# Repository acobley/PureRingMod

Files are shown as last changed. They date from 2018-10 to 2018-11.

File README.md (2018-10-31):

View this project on [CADLAB.io](https://cadlab.io/project/1337). 

# PureRingMod
A Eurorack ring modulator.

1:  Balanced input suitable for a SM58 
2: Carrier and Mod levels should accept 10Vpp.   Level controls on each.
3: Mixer on Mic in and Carrier
4: Mixer on the output of the ring mod chip and Carrier in.  This allows the uint to act as a mic input to eurorack
5: Gain control on the output stage, I found this useful to avoid clipping on the output
6: Dual output sockets.  It's a bugbear of mine that more modules don't have dual output to avoid having to use a splitter module to send the signal to more than one output.

Design Andy C
From a design by Roman Sowa
CC BY 3.0

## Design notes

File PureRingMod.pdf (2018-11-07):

Qty Parts | Description | Value | Package | RS-PART
2 C1, C4 | 10.0¬µF polarized capacitors | 10uF | CPOL-RADIAL-2.5MM-5MM
3 CARRIER, MODULATOR, OUTPUT | | PJ301M-12 | S_JACK
2 D1, D2 | Diode | 1N4148 | DO-1N4148 | 671-5477
5 GAIN, MICMIX, MIX, VOLCARIER, VOLMOD | 100K | Alpha Vertical Potentiometer
1 IC1 | OP AMP | TL074P | DIL14
1 IC2 | OP AMP | TL072P | DIL08
1 MP1 | | AD633AN | DIL08
1 OUTPUT2 | | Output2 | S_JACK
1 POWER | Header 5x2 | M05X2SHD | 2X5-SHROUDED
1 R1 | Resistor | 100K | AXIAL-0.3
1 R10 | Resistor | 27K | AXIAL-0.3
2 R11, R12 | Resistor | 1M | AXIAL-0.3
1 R15 | Resistor | 20K | AXIAL-0.3
3 R2, R13, R16 | Resistor | 10K | AXIAL-0.3
2 R3, R4 | Resistor | 4k7 | AXIAL-0.3
2 R5, R6 | Resistor | 1K | AXIAL-0.3
2 R8, R9 | Resistor | 330 | AXIAL-0.3
1 X1 | Neutrik Audio Connector XLR SERIES NC3FD-V | NC3FD-V | 448-244

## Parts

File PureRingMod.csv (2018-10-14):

Library | Qty | Parts | Description | Value | Package | MF | MPN | OC_FARNELL | OC_NEWARK | PROD_ID | RS-PART | VALUE
INSTRUO | 3 | CARRIER, MODULATOR, OUTPUT |  |  | S_JACK
INSTRUO | 2 | CARRIERAC, MODAC |  |  | TOGGLE_ON_OFF_ON
GMSN | 4 | MICMIX, MIX, VOLCARIER, VOLMOD |  | 9MMPOT | POT
ad633-2 | 1 | MP1 |  | AD633AN | DIL08
SparkFun-Capacitors | 2 | C2, C3 | 0.1µF ceramic capacitors | 1uF | CAP-PTH-SMALL-KIT |  |  |  |  | CAP-08370 |  | 0.1uF
SparkFun-Capacitors | 1 | C5 | 0.1µF ceramic capacitors | 4u7f | CAP-PTH-SMALL-KIT |  |  |  |  | CAP-08370 |  | 0.1uF
SparkFun-Capacitors | 2 | C1, C4 | 10.0µF polarized capacitors | 10uF | CPOL-RADIAL-2.5MM-5MM |  |  |  |  | CAP-08440 |  | 10uF
SparkFun-Resistors | 1 | R14 | 330Ω resistor | 100 | AXIAL-0.3 |  |  |  |  | RES-8371 |  | 330
SparkFun-Resistors | 2 | R1, R16 | 330Ω resistor | 100K | AXIAL-0.3 |  |  |  |  | RES-8371 |  | 330
SparkFun-Resistors | 1 | R13 | 330Ω resistor | 10K | AXIAL-0.3 |  |  |  |  | RES-8371 |  | 330
SparkFun-Resistors | 1 | R5 | 330Ω resistor | 1K | AXIAL-0.3 |  |  |  |  | RES-8371 |  | 330
SparkFun-Resistors | 4 | R6, R7, R11, R12 | 330Ω resistor | 1M | AXIAL-0.3 |  |  |  |  | RES-8371 |  | 330
SparkFun-Resistors | 2 | R2, R15 | 330Ω resistor | 20K | AXIAL-0.3 |  |  |  |  | RES-8371 |  | 330
SparkFun-Resistors | 1 | R10 | 330Ω resistor | 27K | AXIAL-0.3 |  |  |  |  | RES-8371 |  | 330
SparkFun-Resistors | 2 | R8, R9 | 330Ω resistor | 330 | AXIAL-0.3 |  |  |  |  | RES-8371 |  | 330
SparkFun-Resistors | 2 | R3, R4 | 330Ω resistor | 4k7 | AXIAL-0.3 |  |  |  |  | RES-8371 |  | 330
adafruit | 2 | D1, D2 | Diode |  | DO-1N4148
SparkFun-Connectors | 1 | POWER | Header 5x2 | M05X2SHD | 2X5-SHROUDED
con-neutrik_ag | 1 | X1 | Neutrik Audio Connector XLR SERIES | NC3FD-V | NC3FD-V | FARNELL | NC3FDV | 308869 | 07WX7308 |  | 448-244
GMSN-R2Project | 1 | IC2 | OP AMP | TL072P | DIL08
GMSN | 1 | IC1 | OP AMP | TL074P | DIL14

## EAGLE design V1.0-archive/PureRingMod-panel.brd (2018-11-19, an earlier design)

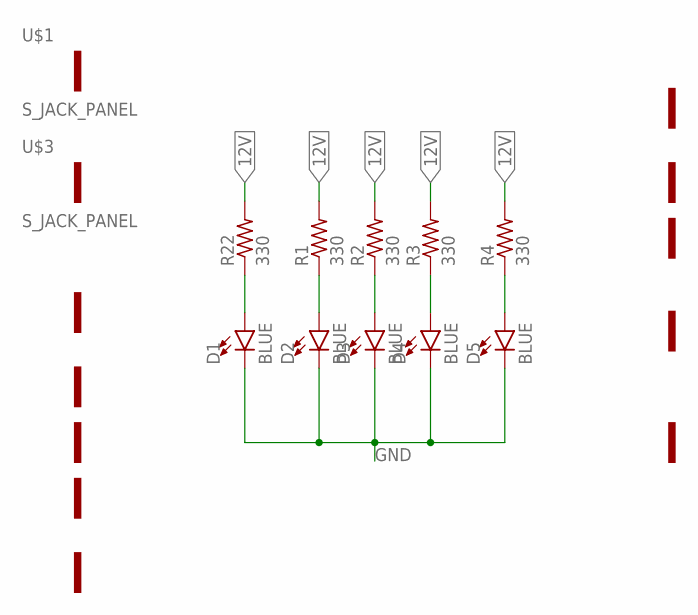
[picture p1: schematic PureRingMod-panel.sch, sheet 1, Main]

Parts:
D1, D2, D3, D4, D5: BLUE; LED-1206
R1, R2, R3, R4, R22: 330; R0805
U$1, U$3: S_JACK_PANEL
U$6, U$7, U$8, U$9, U$10: POT_PANEL
U$11: XLR_PANEL
U$12, U$13, U$14, U$15: MOUNTING_HOLE

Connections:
12V: R1.2, R2.2, R3.2, R4.2, R22.2; also elsewhere on the board
GND: D1.C, D2.C, D3.C, D4.C, D5.C; also elsewhere on the board
unnamed: D1.A, R22.1
unnamed: D2.A, R1.1
unnamed: D3.A, R2.1
unnamed: D4.A, R3.1
unnamed: D5.A, R4.1

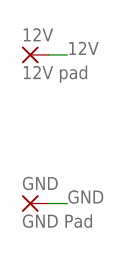
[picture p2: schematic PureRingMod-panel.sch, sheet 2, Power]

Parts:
12V: 12V pad; 1,6/0,8
GND: GND Pad; 1,6/0,8

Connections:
12V: 12V.1; also elsewhere on the board
GND: GND.1; also elsewhere on the board

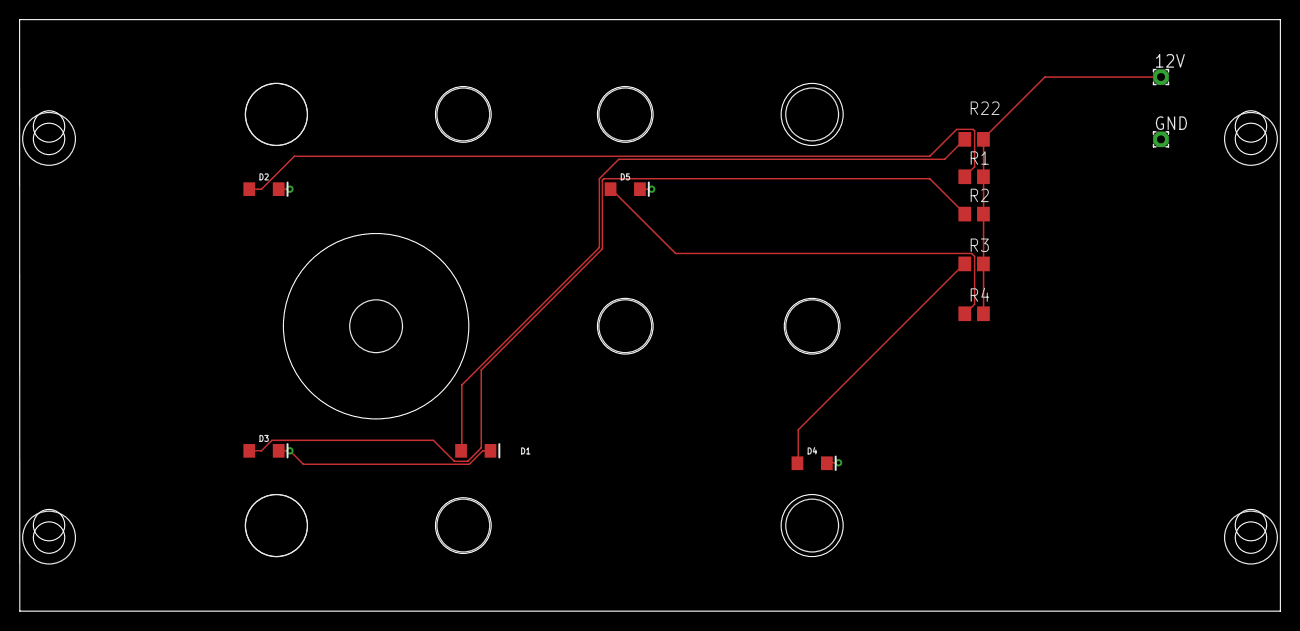
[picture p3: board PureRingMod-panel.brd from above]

Board: 2 copper layers, 128.5 x 60.3 mm, 27 parts (1 on the bottom side), 7 nets.

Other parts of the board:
U$2: GMSN!_LOGO
U$4, U$5: S_JACK_PANEL; S_JACK_PANEL@1

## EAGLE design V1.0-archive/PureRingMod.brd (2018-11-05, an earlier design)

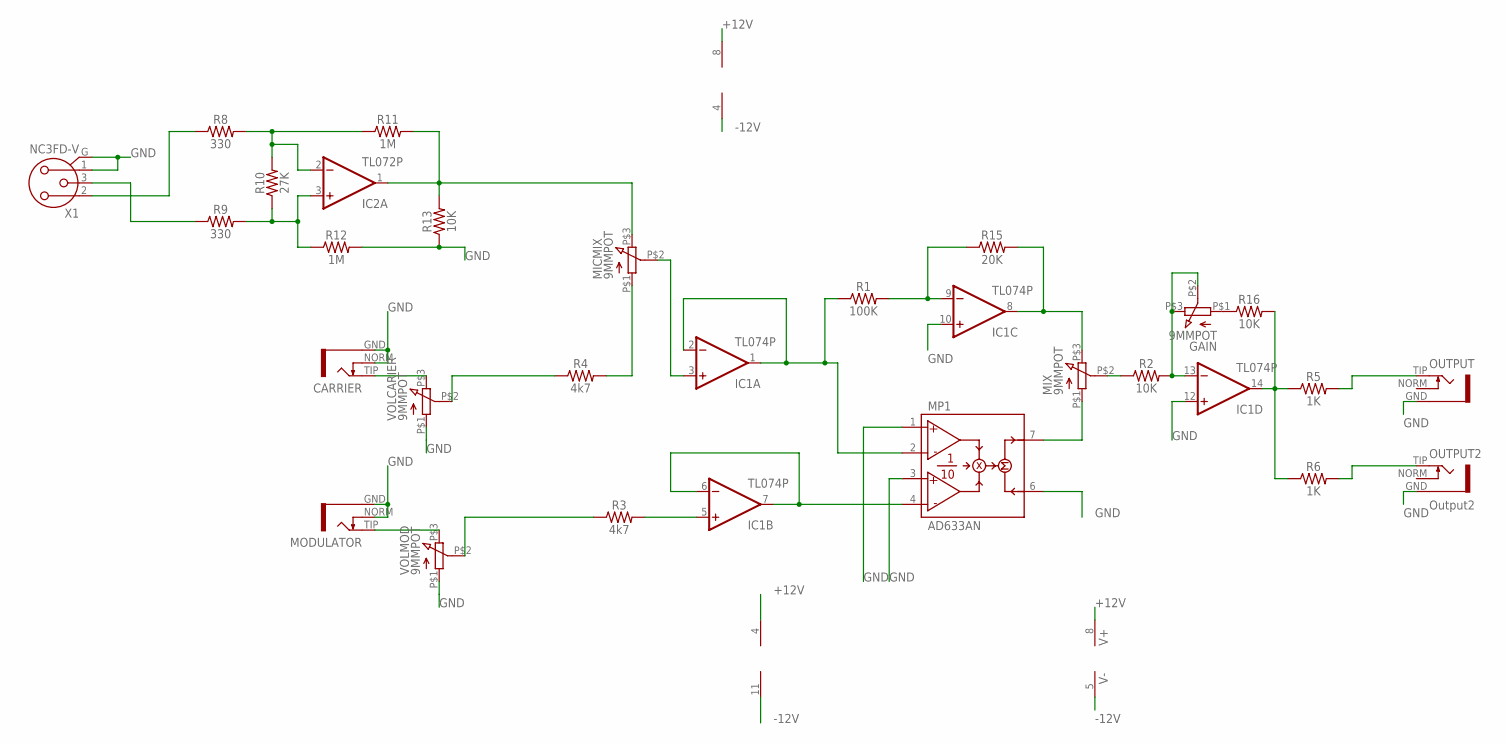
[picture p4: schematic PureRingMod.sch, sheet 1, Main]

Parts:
CARRIER: S_JACK
GAIN: 9MMPOT; POT
IC1: TL074P; DIL14
IC2: TL072P; DIL08
MICMIX: 9MMPOT; POT
MIX: 9MMPOT; POT
MODULATOR: S_JACK
MP1: AD633AN; DIL08
OUTPUT: S_JACK
OUTPUT2: Output2; S_JACK
R1: 100K; AXIAL-0.3
R2, R13, R16: 10K; AXIAL-0.3
R3, R4: 4k7; AXIAL-0.3
R5, R6: 1K; AXIAL-0.3
R8, R9: 330; AXIAL-0.3
R10: 27K; AXIAL-0.3
R11, R12: 1M; AXIAL-0.3
R15: 20K; AXIAL-0.3
VOLCARIER: 9MMPOT; POT
VOLMOD: 9MMPOT; POT
X1: NC3FD-V

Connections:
+12V: IC1.4 (V+), IC2.8 (V+), MP1.8 (V+); also elsewhere on the board
-12V: IC1.11 (V-), IC2.4 (V-), MP1.5 (V-); also elsewhere on the board
GND: CARRIER.GND, CARRIER.NORM, IC1.10 (+IN), IC1.12 (+IN), MODULATOR.GND, MODULATOR.NORM, MP1.1 (X1), MP1.3 (Y1), MP1.6 (Z), OUTPUT.GND, OUTPUT2.GND, R12.P$2 (2), R13.P$1 (1), VOLCARIER.P$1 (1), VOLMOD.P$1 (1), X1.1 (2), X1.G; also elsewhere on the board
unnamed: IC1.1 (OUT), IC1.2 (-IN), MP1.2 (X2), R1.P$1 (1)
unnamed: IC1.6 (-IN), IC1.7 (OUT), MP1.4 (Y2)
unnamed: MIX.P$1 (1), MP1.7 (W)
unnamed: IC1.8 (OUT), MIX.P$3 (3), R15.P$2 (2)
unnamed: GAIN.P$1 (1), R16.P$1 (1)
unnamed: MIX.P$2 (2), R2.P$1 (1)
unnamed: GAIN.P$2 (2), GAIN.P$3 (3), IC1.13 (-IN), R2.P$2 (2)
unnamed: MICMIX.P$1 (1), R4.P$2 (2)
unnamed: IC1.5 (+IN), R3.P$2 (2)
unnamed: IC1.14 (OUT), R5.P$1 (1), R6.P$1 (1), R16.P$2 (2)
unnamed: IC1.9 (-IN), R1.P$2 (2), R15.P$1 (1)
unnamed: OUTPUT.TIP, R5.P$2 (2)
unnamed: CARRIER.TIP, VOLCARIER.P$3 (3)
unnamed: MODULATOR.TIP, VOLMOD.P$3 (3)
unnamed: R4.P$1 (1), VOLCARIER.P$2 (2)
unnamed: R3.P$1 (1), VOLMOD.P$2 (2)
unnamed: OUTPUT2.TIP, R6.P$2 (2)
unnamed: R8.P$1 (1), X1.2 (1)
unnamed: R9.P$1 (1), X1.3
unnamed: IC2.2 (-IN), R8.P$2 (2), R10.P$2 (2), R11.P$1 (1)
unnamed: IC2.3 (+IN), R9.P$2 (2), R10.P$1 (1), R12.P$1 (1)
unnamed: IC2.1 (OUT), MICMIX.P$3 (3), R11.P$2 (2), R13.P$2 (2)
unnamed: IC1.3 (+IN), MICMIX.P$2 (2)

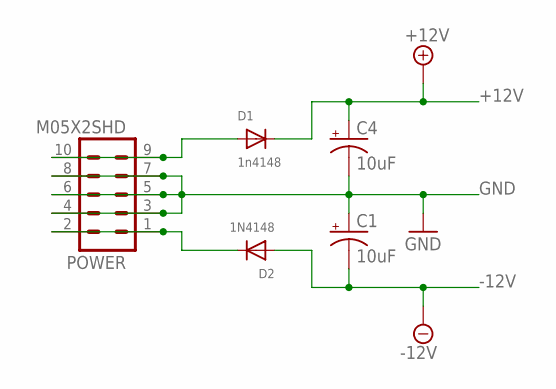
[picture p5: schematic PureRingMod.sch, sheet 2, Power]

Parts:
C1, C4: 10uF; CPOL-RADIAL-2.5MM-5MM
D1: 1n4148; DO-1N4148
D2: 1N4148; DO-1N4148
POWER: M05X2SHD; 2X5-SHROUDED

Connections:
+12V: C4.1 (+), D1.C; also elsewhere on the board
-12V: C1.2 (-), D2.A; also elsewhere on the board
GND: C1.1 (+), C4.2 (-), POWER.3, POWER.4, POWER.5, POWER.6, POWER.7, POWER.8; also elsewhere on the board
unnamed: D1.A, POWER.9, POWER.10
unnamed: D2.C, POWER.1, POWER.2

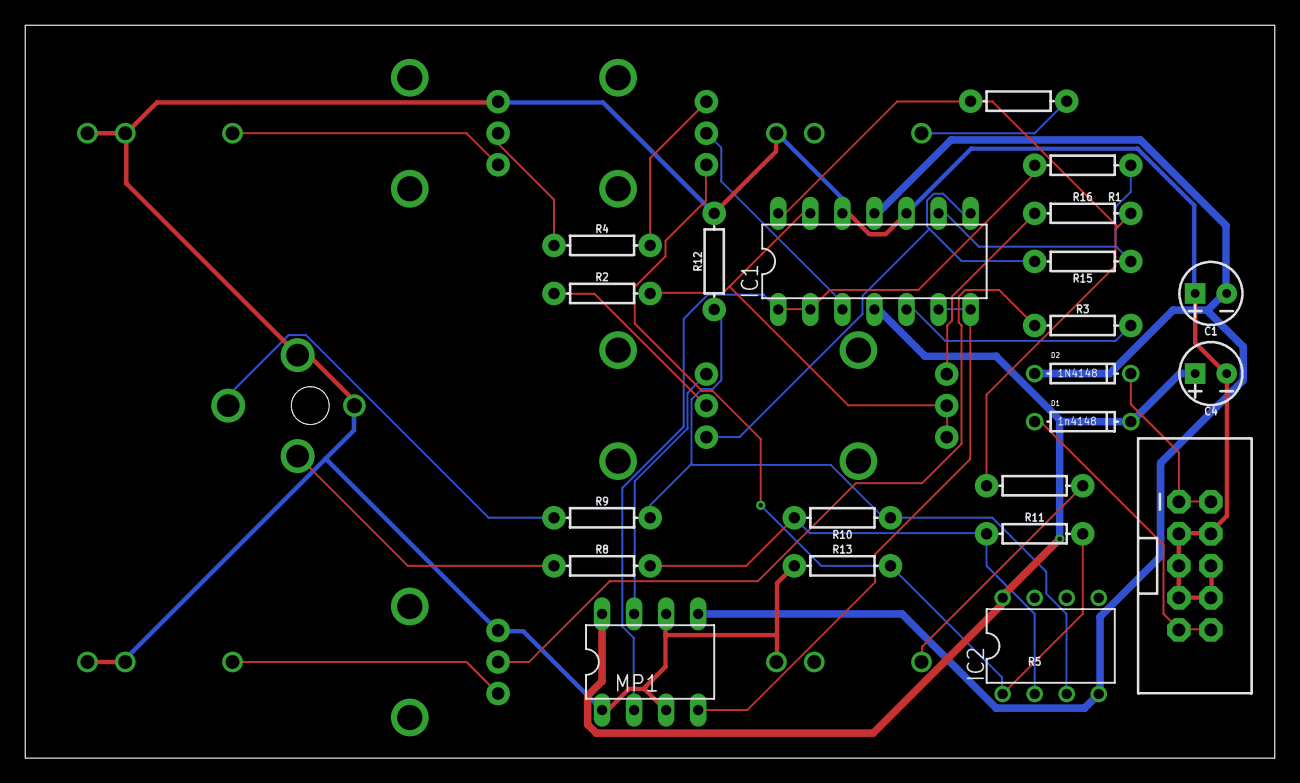
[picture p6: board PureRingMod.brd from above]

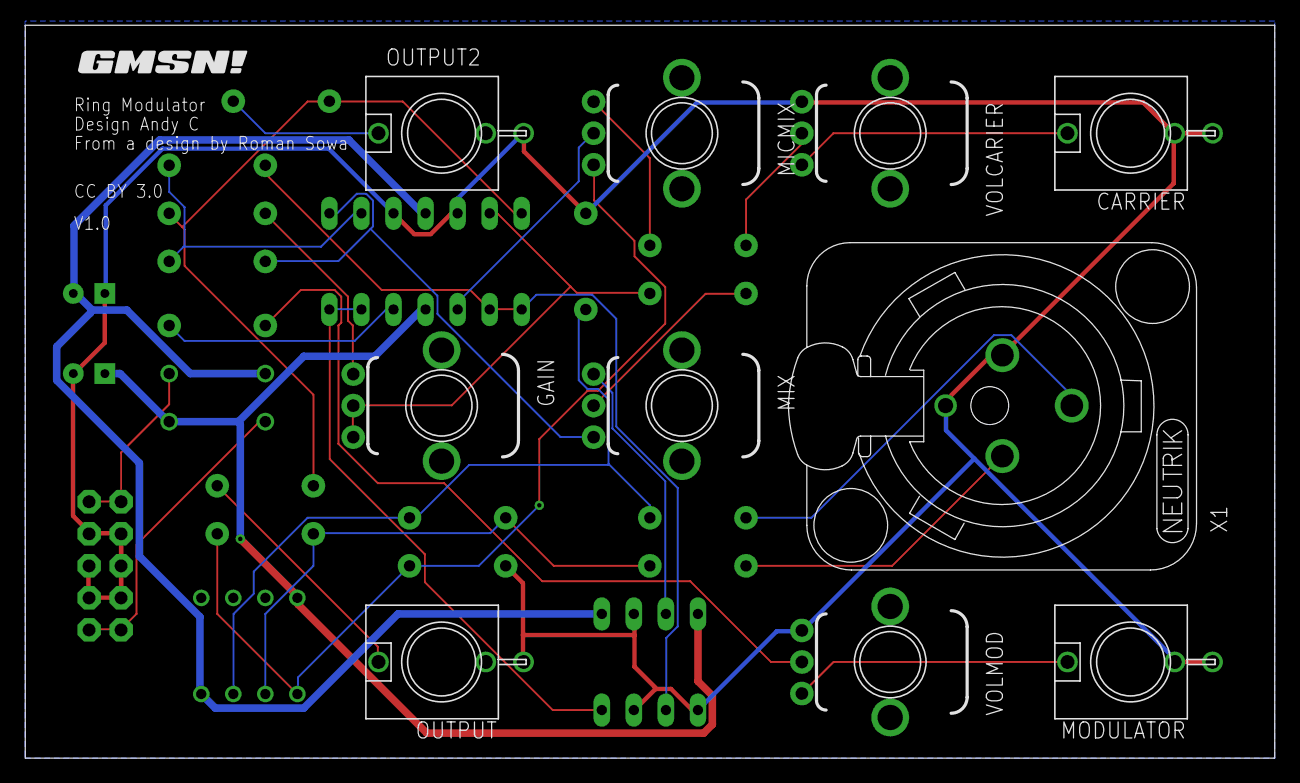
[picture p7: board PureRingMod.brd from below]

Board: 2 copper layers, 99.0 x 58.1 mm, 33 parts (11 on the bottom side), 28 nets.

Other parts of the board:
U$2: GMSN!_LOGO

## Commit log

2018-10-03 Init design
    [PureRingMod.brd, PureRingMod.sch]
2018-10-03 Power to TL072
2018-10-13 added mix control
    [PureRingMod.brd, PureRingMod.sch]
2018-10-13 Added input circuit emualtion for use in https://www.falstad.com/circuit/
2018-10-13 updated components in feedback circuit of preamp
    [PureRingMod.brd, PureRingMod.sch]
2018-10-13 Corrected values on input circuit
    [PureRingMod.brd, PureRingMod.sch]
2018-10-13 corrected input components
    [PureRingMod.brd, PureRingMod.sch]
2018-10-14 added missing parts
    [PureRingMod.brd, PureRingMod.csv, PureRingMod.sch]
2018-10-14 Changed output circuit values
    [PureRingMod.brd, PureRingMod.csv, PureRingMod.sch]
2018-10-14 modified input mic circuit
    [PureRingMod.brd, PureRingMod.csv, PureRingMod.sch]
2018-10-14 Fixed input
    [PureRingMod.brd, PureRingMod.sch]
2018-10-14 Fixed output socket
    [PureRingMod.brd, PureRingMod.sch]
2018-10-19 fixed -12V to Tl074
    [PureRingMod.brd, PureRingMod.sch]
2018-10-19 removed ac/Dc switched input
    [PureRingMod.brd, PureRingMod.sch]
2018-10-19 ripped up board
    [PureRingMod.brd]
2018-10-21 Fixed wiring errors
    [PureRingMod.brd, PureRingMod.sch]
2018-10-27 updated board
    [PureRingMod.brd]
2018-10-31 V1.0 board
    [PureRingMod.brd, PureRingMod.sch]
2018-11-01 added panel design (PCB)
    [PureRingMod-panel.brd, PureRingMod-panel.sch]
2018-11-01 Panel Design
    [PureRingMod-panel.brd]
2018-11-03 design of panel
    [PureRingMod-panel.brd, PureRingMod.brd]
2018-11-05 added BOM
    [PureRingMod.xlsx]
2018-11-05 updated BOM
    [PureRingMod.brd, PureRingMod.sch, PureRingMod.xlsx]
2018-11-07 upadeted panel
    [PureRingMod-panel.brd, PureRingMod-panel.sch]
2018-11-07 latest panel board using 'components'
    [PureRingMod-panel.brd, PureRingMod-panel.sch]
2018-11-19 frozen V1.0 directory
    [PureRingMod-panel.brd, PureRingMod-panel.sch, PureRingMod.brd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]
2018-11-29 Panel layout and routing
    [PureRingMod-panel.brd, PureRingMod-panel.sch, PureRingMod.brd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]
2018-11-29 Added Version 1 archive
    [PureRingMod-panel.brd, PureRingMod-panel.sch, PureRingMod.brd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]

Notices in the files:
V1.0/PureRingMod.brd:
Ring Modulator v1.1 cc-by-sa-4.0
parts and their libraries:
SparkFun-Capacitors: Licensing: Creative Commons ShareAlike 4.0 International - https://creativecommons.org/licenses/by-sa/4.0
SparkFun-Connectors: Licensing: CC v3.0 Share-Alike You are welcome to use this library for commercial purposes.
